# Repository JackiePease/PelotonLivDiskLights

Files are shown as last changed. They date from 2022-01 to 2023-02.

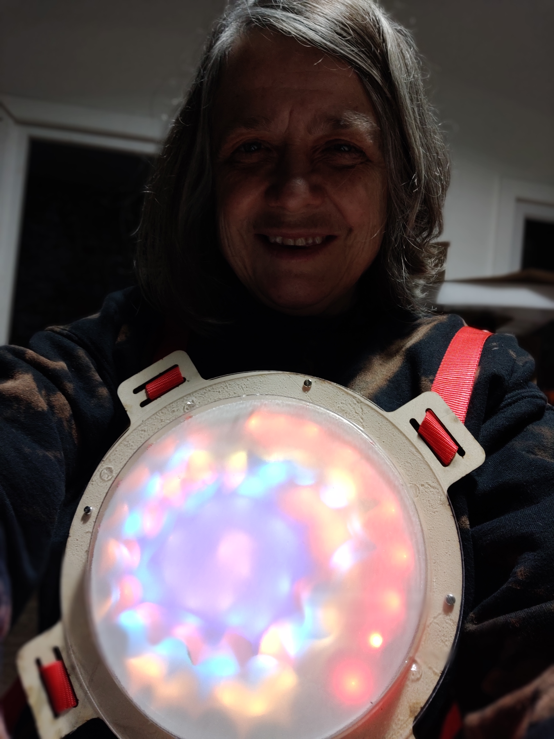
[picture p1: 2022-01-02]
assets/me-wearing-prototype.jpg

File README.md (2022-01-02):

# PelotonLivDiskLights
An Autumn 2021 project to provide 10 sets of wearable lights for Peloton Liverpool Joy Ride winter cycling events (e.g. https://youtu.be/Y08svOdIMxA) produced by a group of volunteers from DoES Liverpool and Peloton Liverpool. It uses the [MCQN My Bike's Got LED board](github.com/mcqn/my-bikes-got-led) which was originally designed by Adrian McEwen for [lights attached to bike frames](https://mcqn.com/posts/week-842-all-about-active-travel/?utm_source=dlvr.it&utm_medium=twitter) but is equally good for most situations involving battery powered addressable LEDs.

The lights consist of large circular disks on the front and back of each cyclist, attached with webbing straps. Each contains a disk of 93 addressable LEDs. The board and battery (4 x 18650) are in a waterproof(ish) pouch which is taped to the back of the front disk with VHB tape. Leads go from the board to the lights through holes in the back of the disks. These are taped over with plumbing tape to increase water resistance. The leads to the back disk are taped to one of the shoulder straps.

I started prototyping based on the children's backpacks shown on pages 10 and 11 of [this document](http://torquetorque.net/wp-content/uploads/CriticalKitsAndHow%20WeUseThem.pdf) as these had been donated to DoES Liverpool. I quickly found that the combination of electrical leads and cross over straps made them very confusing to put on and ended up using separate straps for each shoulder and both sides of the body. I was able to reuse the webbing and clips from this project though, as well as some leftover hook and loop tape and marking tape from a visor project.

I vacuum formed the front face of the disks with help from Matt and Jimmy of the University of Liverpool School of Engineering (Matt is a member of the cycling group). The face of the front disks is made of 1mm thick white HIPS plastic giving a very diffused efffect to the lights underneath. The face of the back disks is made of 1mm clear PETG. The Engineering Department made a former from MDF which led to a slightly rough surface giving a slight but useful diffused effect to the clear side. The back face of all the disks was laser cut from 1mm HIPS. As this was quite thin, I decided to cut the front face to the same shape, hoping that this would help reinforce it.

Originally we were going to use strips of lights set out in a grid, but this turned out to be too time consuming and difficult to lay out and solder. We then ordered some disks in the form of concentric rings (similar to [these](https://www.aliexpress.com/item/4000352752774.html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). The ones we got had 93 lights. When they arrived, they had leads soldered on to each ring so that the rings could be split up and used separately. Although they worked like this, they wouldn't fit into the available space, so Paul H and Sean J desoldered them and resoldered them together. The light disks take less space than the original grid, but we decided to go ahead with the original size of container, as these had already been produced. In addition I tried a modified version of the attachment points, using vertical and horizontal attachments instead of diagonal - this was a slight improvement, but I decided to use the existing laser cut backs as these had alreday been made, and we might see need for further changes when they are in use.

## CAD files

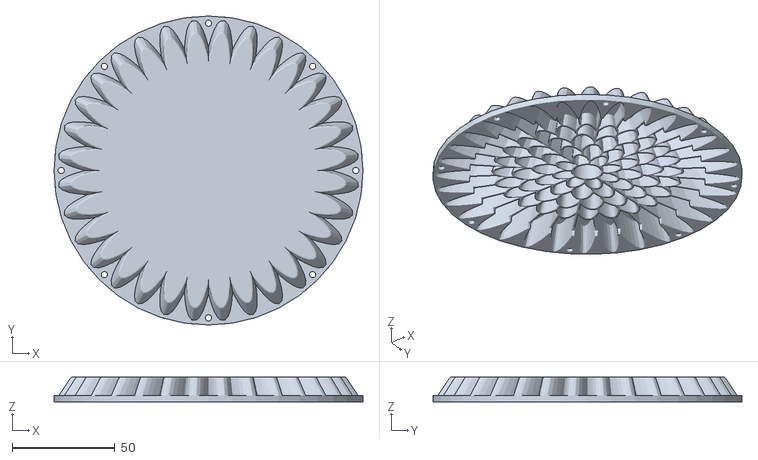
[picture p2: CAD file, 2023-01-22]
3d-printing-files/alison_bikelights.stl
150.0 x 150.0 x 12.0

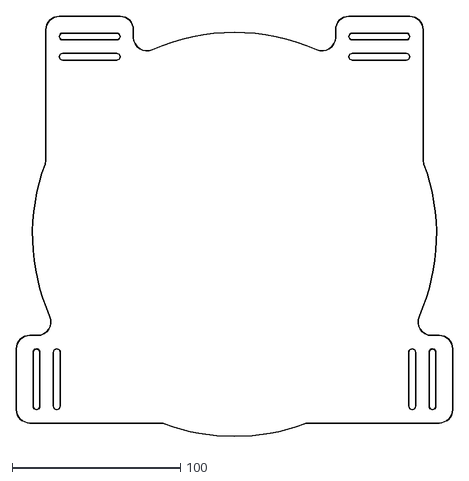
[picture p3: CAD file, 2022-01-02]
laser-cutting-files/adjusted_back_plate.dxf
259.1 x 252.1

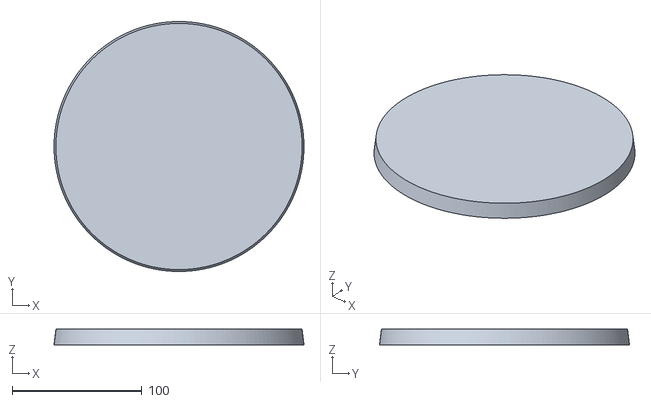
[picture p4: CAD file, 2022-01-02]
laser-cutting-files/former.stl
192.9 x 192.9 x 12.0

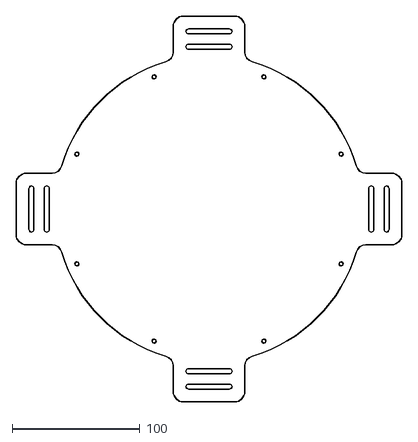
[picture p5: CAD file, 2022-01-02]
laser-cutting-files/back_plate.dxf
302.0 x 302.0

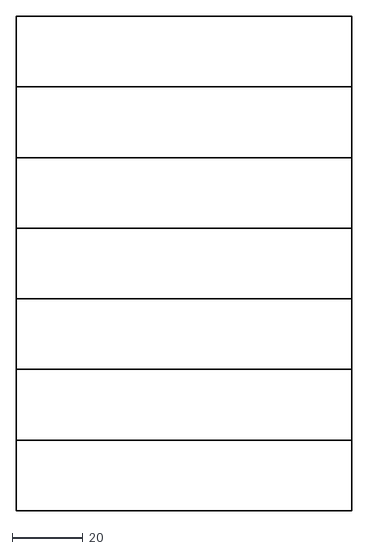
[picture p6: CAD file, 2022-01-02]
laser-cutting-files/spacer_strips.dxf
95.0 x 140.0

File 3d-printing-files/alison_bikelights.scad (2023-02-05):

frameThickness=1;
centreCircleDiameter=15;
fn=100;
ledsInRing=[1, 8, 12, 16, 24, 32];
ringRadius=[7.5, 10, 10, 10, 10, 27];
ringAmplitude=[7, 7, 7, 7, 7, 17];
noRings=6;
height=14;
diskRadius=115/2;
diskIndent=5;
plateRadius=100;
slope=0.9;
boltDiameter=3;
numBolts=8;
brimDepth=1.5;
boltInclude=[2,5,10,13,18,21,26,29];
difference(){
    union(){
        rotate([0,0,180/ledsInRing[noRings - 1]])
        translate([0,0,(height-frameThickness)/2])
        minkowski(){
             linear_extrude(height = height-frameThickness, center = true, $fn = fn, scale = slope){
                 bumpy_loop(sum(ringRadius, noRings-1)-frameThickness/2, ledsInRing[noRings-1], ringAmplitude[noRings-1]);
             }
             sphere(r=frameThickness, $fn=fn);
         } 
         linear_extrude(height = brimDepth, center = false, $fn = fn){
             difference(){
                 circle(r = sum(ringRadius, noRings-1) + frameThickness/2);
    
                 for (m = [0:1:numBolts - 1]){
                      rotate([0,0,(boltInclude[m] * 360/ledsInRing[noRings-1]) + 180/ledsInRing[noRings-1]])
                      translate([sum(ringRadius, noRings-1) - 3*boltDiameter/2,0,0])
                      circle(r=boltDiameter/2);
                  }
             }
         } 
     } 
     intersection(){
       rotate([0,0,180/ledsInRing[noRings-1]])
       translate([0,0,(height-frameThickness)/2])
       linear_extrude(height = height-frameThickness, center = true, $fn = fn, scale = slope){
             bumpy_loop(sum(ringRadius, noRings-1)-frameThickness/2, ledsInRing[noRings-1], ringAmplitude[noRings-1]);
        }   
        linear_extrude(height = height-frameThickness, center = false, $fn = fn, scale = 1){
            for (j = [0:1:noRings-1]){
                makeRing(j);
             }
        } 
     }    
     cylinder(h=diskIndent*2, r=diskRadius, $fn=fn, center=true);
     translate([0, 0, -sum(ringRadius, noRings-1)])
     cube([sum(ringRadius, noRings-1)*3,sum(ringRadius, noRings-1)*3,sum(ringRadius, noRings-1)*2],true);
}


module makeRing(j){
    
if (j == 0){
    circle(r=ringRadius[j] - frameThickness/2, $fn=fn);
    }

else 
    {difference(){ 
            radiusOuter = sum(ringRadius, j);
            offset(-frameThickness/2)
              rotate([0,0,180/ledsInRing[j]])
              bumpy_loop(radiusOuter, ledsInRing[j], ringAmplitude[j]);
            if (j > 1){
              radiusOuter1 = sum(ringRadius, j-1);
              offset(frameThickness/2)
                rotate([0,0,180/ledsInRing[j-1]])
                bumpy_loop(radiusOuter1, ledsInRing[j-1], ringAmplitude[j-1]);
            }  
            else {
              // circle(r=ringRadius[j-1] + frameThickness/2);
              offset(frameThickness/2)
                circle(r=ringRadius[j-1]);
            }
             
        // radiating lines
           if (j > 0){              
              radiusOuter2 = sum(ringRadius, j);
              radiusInner2 = sum(ringRadius, j-1);
              rotate([0,0,180/ledsInRing[j]]) 
              for (k = [0:1:ledsInRing[j]/2 - 1]){
                  translate([0,0,0])
                  rotate([0,0,(k*360/ledsInRing[j]) - 360/ledsInRing[j]])
                    square([radiusOuter2*2, frameThickness], center = true);
              }
           }
       }
    }
}

function sum(a,i)=(i==0)?a[0]:a[i]+sum(a,i-1);

module bumpy_loop(r, bumpsx2, amplitude) {
    bumps = bumpsx2/2;
    avR = r - amplitude;
    union(){
        polygon(points=[for (th = [0 : 360]) [
            cos(th) * (avR + sin(th * bumps) * amplitude),
            sin(th) * (avR + sin(th * bumps) * amplitude)
        ]]);
   
        polygon(points=[for (th = [0 : 360]) [
            cos(th) * (avR + sin((th + 180/bumps) * bumps) * amplitude),
            sin(th) * (avR + sin((th + 180/bumps) * bumps) * amplitude)
        ]]);
    }
}

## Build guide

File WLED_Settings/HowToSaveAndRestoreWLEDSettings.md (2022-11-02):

See https://github.com/Aircoookie/WLED/issues/146 for how to save and restore WLED settings. To download:

[WLED-IP]/edit?download=cfg.json
[WLED-IP]/edit?download=presets.json

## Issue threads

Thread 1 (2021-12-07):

Currently possible to reset the lights to factory settings

JackiePease, 2021-12-07:
The code needs to be changed to not allow this, as it is easy to knock the reset button when moving the battery.
Alternatively Mike G suggested making a cover for the reset button

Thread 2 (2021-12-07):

It could be useful to be able to send left and right arrow bit maps to all the DiskLights

JackiePease, 2021-12-07:
The ride leader could send left and right arrow bit maps to all the DiskLights to tell riders which direction to go. Maybe this could be done through a phone app, or by buttons attached to their handlebars.

JackiePease, 2021-12-07:
It would also be useful to be able to send other patterns and sequences to all the DiskLights

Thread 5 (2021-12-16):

It would be useful to be able to drive the front and back disks with separate data

JackiePease, 2021-12-16:
It would be useful to be able to drive the front and back disks with separate data, for example if you want to display a pattern on the front disk and a direction indicator on the back one.
At the moment both sets of lights are controlled from the same pin. I didn't do them as one long strip as this would have required an extra lead between front and back (in the end this might not have been two much of an issue as the power and ground leads go over the shoulder anyway).

JackiePease, 2021-12-16:
This page has some useful info: [https://github.com/Aircoookie/WLED/wiki/Multi-strip](https://github.com/Aircoookie/WLED/wiki/Multi-strip)

JackiePease, 2021-12-16:
I downloaded WLED v00.12.0 to an ESP8266 Lolin using install.wled.me and connected WS2812 rings to pins 1 and 2 (TX and D4).
The "Hardware setup" section is in "LED Preferences",  after the LED settings. Setting pin 1 to start at 0 with count of 8 and pin 2 to start at 8 with a count of 8 seems to work. The program then treats the lights as if they were connected serially and you can then use segments to set them to different patterns. I need to find out which pins the MyBikesGotLED board uses.

JackiePease, 2021-12-16:
It looks like the MyBikesGotLED board uses GPIO0 (D3 on Lolin board) for clock. I've tried that and it works with the test setup. The Multi-strip page says "You can use any other pin, but it will use the bitbang method, which is not recommended for reliability" so more testing will be needed.

JackiePease, 2022-01-26:
Closed as doesn't seem feasible to use with this number of lights

Closed 2022-01-26.

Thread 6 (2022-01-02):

LED disks becoming detached from the back board of the outer casing

JackiePease, 2022-01-02:
In use, some of the LED disks have detached from the back board of the outer casing.

JackiePease, 2022-01-02:
The backs of the LED disks aren't flat because of solder and hot glue, so I used plywood spacers. The plywood was attached to the backing board with carpet tape and to the LED disks with stick on hook and loop tape. Although this worked for a while, it seems that this method is not suitable for long term use, and some of the disks have come unstuck.

I have replaced the plywood strips in set 4 (both sides), set 6 (clear side), and set 3 (white side) with acrylic spacers, which seems to give better adhesion with the hook and loop tape. I used VHB tape to stick the acrylic spacers to the HIPS backing board.

As the construction all of the disk lights is the same, it is likely that other lights will also fail. I'm leaving them for the moment though, in case anything else needs to be changed - it takes a while to remove the VHB tape that holds the front and back parts of the outer casing together (with a scalpel) and the HIPS plastic is easy to crack.

JackiePease, 2022-01-14:
Replaced plywood strips in set 8 (clear side)

JackiePease, 2022-01-14:
Replaced plywood strips in set 6 (clear side)

JackiePease, 2022-01-26:
Replaced plywood strips in clear sides of 4 and 7

JackiePease, 2022-03-06:
Replaced plywood strips in white side of 4

JackiePease, 2022-04-19:
Replaced plywood strips in white side of 8 and [unidentified] disk

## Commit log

2022-01-02 Added photos and laser cutting files
    [adjusted_back_plate.dxf, back_plate.dxf, former.stl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]
2023-01-17 Added wip front face of bikelight for Alison
    [alison_bikelights.scad, alison_bikelights.stl]
2023-01-22 Changed file
    [alison_bikelights.scad, alison_bikelights.stl]
2023-01-28 Made inner petals vertical, changed base thickness
    [alison_bikelights.scad]
2023-02-04 Changed bolt spacing
    [alison_bikelights.scad]
2023-02-05 Deeper insert for LED disk, moved bolts
    [alison_bikelights.scad]
